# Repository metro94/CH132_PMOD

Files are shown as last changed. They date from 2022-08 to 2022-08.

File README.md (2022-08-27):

# CH132_PMOD: Dual PMOD module for WCH CH132H (USB PHY)

Used for testing WCH CH132H. Test passed for Lattice ECP5 FPGA.

Compatible with Digilent PMOD specification (300 mil apart).

The trace lengths of ULPI signals are **NOT** the same. It's not that it can't be used, right?

CH132 PMOD

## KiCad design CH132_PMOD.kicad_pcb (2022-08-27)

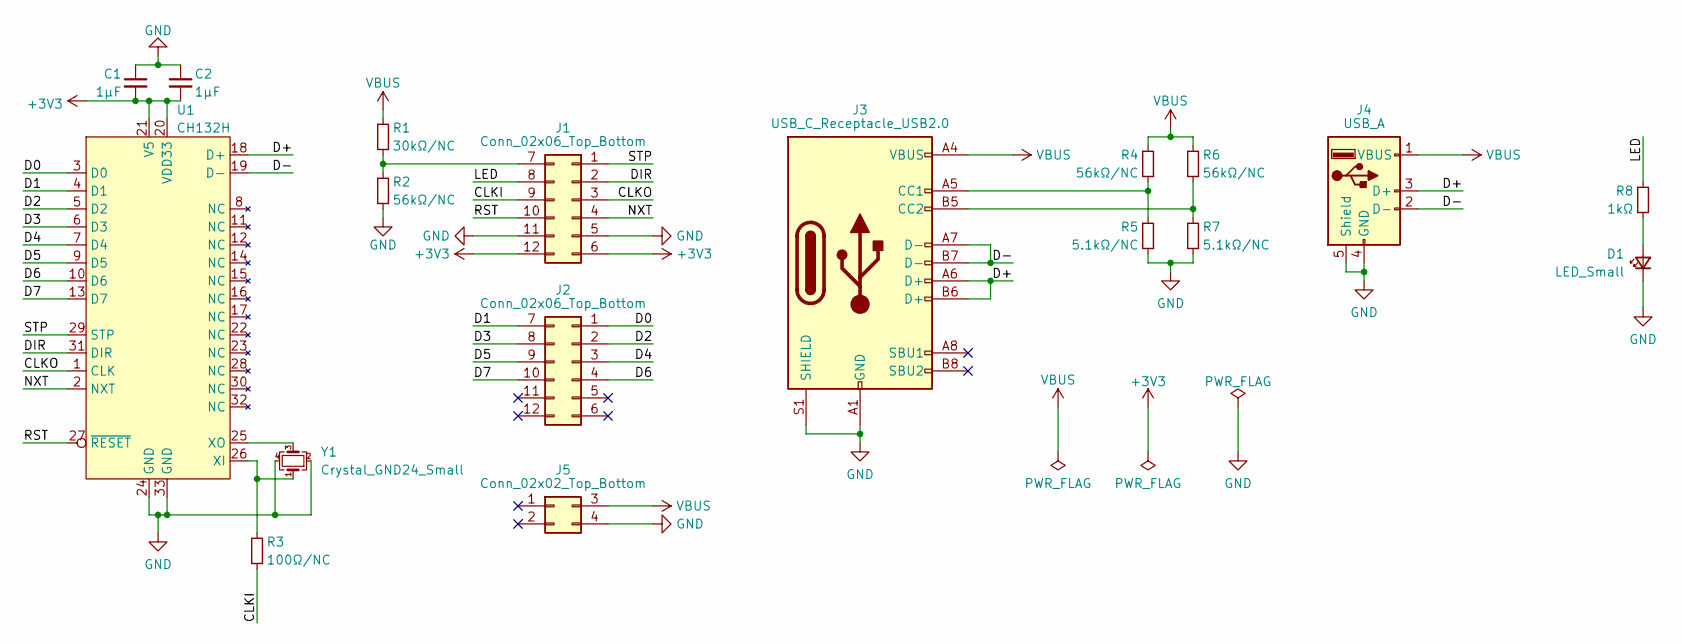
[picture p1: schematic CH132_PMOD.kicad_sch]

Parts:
C1, C2: 1μF; C_0805_2012Metric_Pad1.18x1.45mm_HandSolder
D1: LED_Small; LED_0805_2012Metric_Pad1.15x1.40mm_HandSolder
J1, J2: Conn_02x06_Top_Bottom; Pmod_Dual
J3: USB_C_Receptacle_USB2.0; USB_C_Receptacle_HRO_TYPE-C-31-M-12
J4: USB_A; USB_A_CONNFLY_DS1095-WNR0
J5: Conn_02x02_Top_Bottom; EdgePads_01x02_Open
R1: 30kΩ/NC; R_0805_2012Metric_Pad1.20x1.40mm_HandSolder
R2, R4, R6: 56kΩ/NC; R_0805_2012Metric_Pad1.20x1.40mm_HandSolder
R3: 100Ω/NC; R_0805_2012Metric_Pad1.20x1.40mm_HandSolder
R5, R7: 5.1kΩ/NC; R_0805_2012Metric_Pad1.20x1.40mm_HandSolder
R8: 1kΩ; R_0805_2012Metric_Pad1.20x1.40mm_HandSolder
U1: CH132H; QFN-32-1EP_5x5mm_P0.5mm_EP3.3x3.3mm
Y1: Crystal_GND24_Small; Crystal_SMD_SeikoEpson_TSX3225-4Pin_3.2x2.5mm_HandSoldering

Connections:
+3V3: C1.2, C2.2, J1.6, J1.12, U1.20 (VDD33), U1.21 (V5)
/CLKI: J1.9, R3.2
/CLKO: J1.3, U1.1 (CLK)
/D0: J2.1, U1.3 (D0)
/D1: J2.7, U1.4 (D1)
/D2: J2.2, U1.5 (D2)
/D3: J2.8, U1.6 (D3)
/D4: J2.3, U1.7 (D4)
/D5: J2.9, U1.9 (D5)
/D6: J2.4, U1.10 (D6)
/D7: J2.10, U1.13 (D7)
/D+: J3.A6 (D+), J3.B6 (D+), J4.3 (D+), U1.18 (D+)
/D-: J3.A7 (D-), J3.B7 (D-), J4.2 (D-), U1.19 (D-)
/DIR: J1.2, U1.31 (DIR)
/LED: J1.8, R8.1
/NXT: J1.4, U1.2 (NXT)
/RST: J1.10, U1.27 (~RESET)
/STP: J1.1, U1.29 (STP)
GND: C1.1, C2.1, D1.1 (K), J1.5, J1.11, J3.A1 (GND), J3.A12 (GND), J3.B1 (GND), J3.B12 (GND), J3.S1 (SHIELD), J4.4 (GND), J4.5 (Shield), J5.4, R2.2, R5.2, R7.2, U1.24 (GND), U1.33 (GND), Y1.2, Y1.4
unnamed: D1.2 (A), R8.2
unnamed: J1.7, R1.2, R2.1
unnamed: J3.A5 (CC1), R4.2, R5.1
unnamed: J3.B5 (CC2), R6.2, R7.1
unnamed: R3.1, U1.26 (XI), Y1.1
unnamed: U1.25 (XO), Y1.3
VBUS: J3.A4 (VBUS), J3.A9 (VBUS), J3.B4 (VBUS), J3.B9 (VBUS), J4.1 (VBUS), J5.3, R1.1, R4.1, R6.1

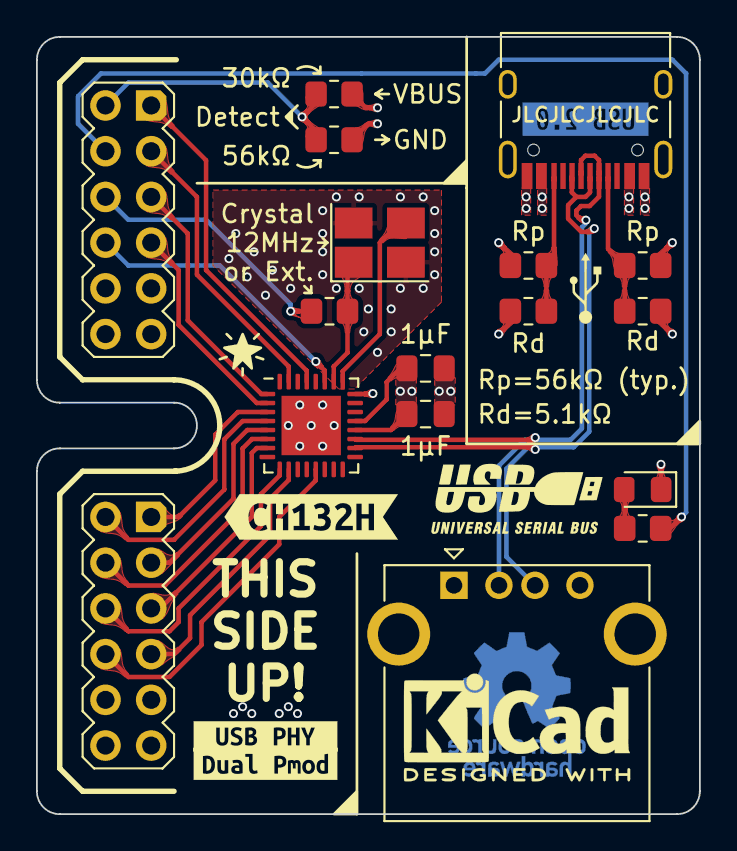
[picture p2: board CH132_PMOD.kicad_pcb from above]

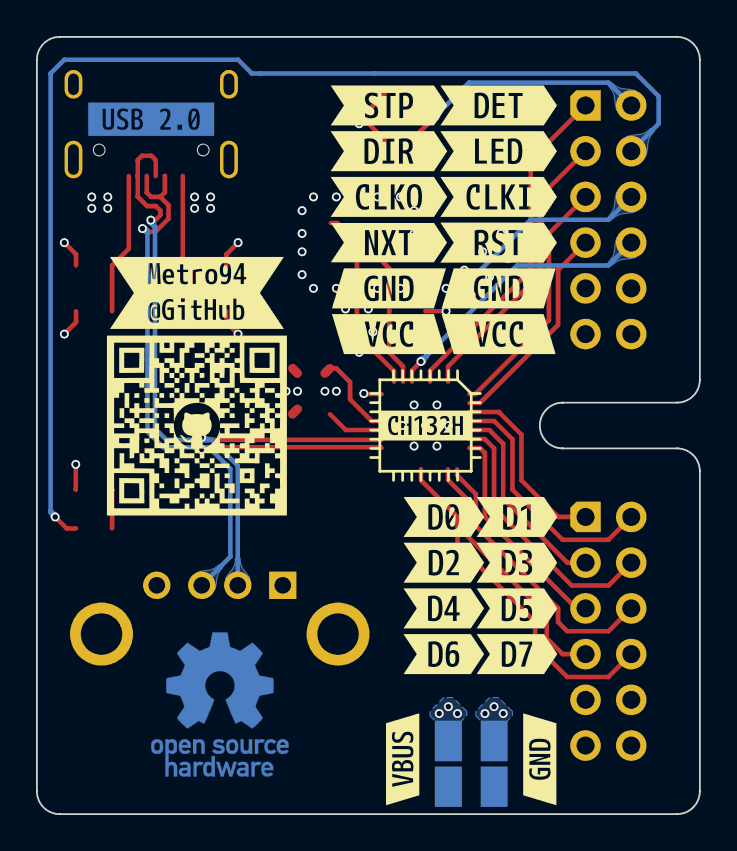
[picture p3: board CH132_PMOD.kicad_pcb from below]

Board: 4 copper layers, 36.8 x 43.2 mm, 48 parts (27 on the bottom side), 26 nets.

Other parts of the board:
REF1: KiCad-Logo2_5mm_SilkScreen
REF2: OSHW-Logo_7.5x8mm_Copper
kibuzzard-62DB6A52: G***; kibuzzard-62DB6A52
kibuzzard-62DB6C7E: G***; kibuzzard-62DB6C7E
kibuzzard-62DB6C9E: G***; kibuzzard-62DB6C9E
kibuzzard-62DB6C88: G***; kibuzzard-62DB6C88
kibuzzard-62DB6C95: G***; kibuzzard-62DB6C95
kibuzzard-62DB6D44, kibuzzard-62DB6D44#2: G***; kibuzzard-62DB6D44
kibuzzard-62DB6D54, kibuzzard-62DB6D54#2: G***; kibuzzard-62DB6D54
kibuzzard-62DB6E8D: G***; kibuzzard-62DB6E8D
kibuzzard-62DB6E9D: G***; kibuzzard-62DB6E9D
kibuzzard-62DB6E72: G***; kibuzzard-62DB6E72
kibuzzard-62DB6EAA: G***; kibuzzard-62DB6EAA
kibuzzard-62DB6F6C: G***; kibuzzard-62DB6F6C
kibuzzard-62DB6F17: G***; kibuzzard-62DB6F17
kibuzzard-62DB6F29: G***; kibuzzard-62DB6F29
kibuzzard-62DB6F45: G***; kibuzzard-62DB6F45
kibuzzard-62DB6F50: G***; kibuzzard-62DB6F50
kibuzzard-62DB6F58: G***; kibuzzard-62DB6F58
kibuzzard-62DB6F64: G***; kibuzzard-62DB6F64
kibuzzard-62DB6F73: G***; kibuzzard-62DB6F73
kibuzzard-62DB60FD: G***; kibuzzard-62DB60FD
kibuzzard-62DB724E: G***; kibuzzard-62DB724E
kibuzzard-62DB6272: G***; kibuzzard-62DB6272
kibuzzard-62DB6291: G***; kibuzzard-62DB6291
kibuzzard-62DB7427: G***; kibuzzard-62DB7427
kibuzzard-62DB8401: G***; kibuzzard-62DB8401
kibuzzard-62DB8417: G***; kibuzzard-62DB8417
